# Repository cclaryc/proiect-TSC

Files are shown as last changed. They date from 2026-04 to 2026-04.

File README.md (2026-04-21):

# Overview - Hector Watch

Proiectul **Hector Watch** vizează dezvoltarea unui smartwatch, optimizat pentru consum redus de energie. Sistemul este construit în jurul microcontrolerului **nRF52840** și utilizează un afișaj de tip **e-Paper** de 1.54 inch.

### 1. Arhitectura Hardware și Selecția Componentelor
Această etapă a constat în definirea specificațiilor și alegerea componentelor pentru eficiență energetică maximă:
* **Unitate centrală:** nRF52840 (SoC cu suport BLE 5.3).
* **Afișaj:** Panou E-Ink Waveshare 1.54".
* **Senzori și Feedback:** Accelerometru Bosch BMA423 (I2C) și driver haptic TI DRV2605.
* **Sursă de energie:** Baterie Li-Po 250mAh .

## Functional Architecture

Arhitectura funcțională este proiectată pentru a maximiza eficiența energetică și a asigura o comunicare fluidă între procesorul central și perifericele specializate.

### 1. Sistemul de Management al Energiei (PMU)
Acest subsistem asigură alimentarea continuă și protecția circuitelor:
* **Input:** USB-C (5V) pentru încărcare.
* **Încărcare și Protecție:** Realizată prin IC1 , care gestionează ciclul de încărcare al bateriei Li-Po.
* **Monitorizare (Fuel Gauge): U3 raportează starea de încărcare (SoC) și tensiunea bateriei prin I2C.
* **Reglare:** IC2 (Buck-Boost) transformă tensiunea variabilă a bateriei într-o tensiune stabilă de **3.3V** pentru restul componentelor.

### 2. Procesare și Conectivitate
* **Core:** **nRF52840** (ARM Cortex-M4F) rulează logica ceasului și gestionează stack-ul de Bluetooth Low Energy (BLE).
* **Timing:** Cristale externe de 32MHz (precizie procesor) și 32.768kHz (precizie ceas/RTC în mod sleep).

### 3. Interfața Om-Mașină (HMI)
* **Output Vizual:** Ecranul **E-Ink** (cerneală electronică) reține imaginea fără consum de curent, fiind actualizat prin protocolul **SPI**. 
* **Output Haptic:** Driver-ul U2 traduce comenzile I2C în vibrații mecanice prin motorul de tip coin.
* **Input:** Trei butoane fizice (GPIO) pentru navigare și interacțiune.

### 4. Subsistemul de Senzori
* Accelerometrul **BMA423** monitorizează activitatea fizică și detectează orientarea încheieturii pentru activarea ecranului.

### Block Diagram

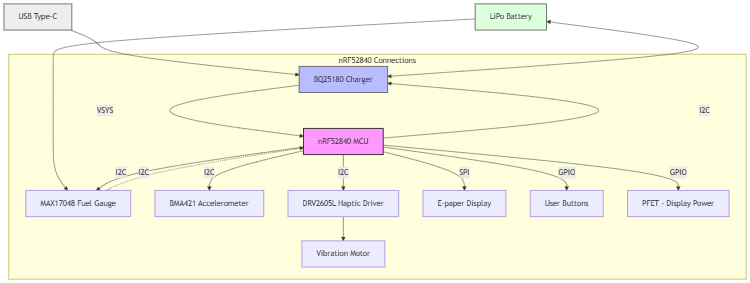
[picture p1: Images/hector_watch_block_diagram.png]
Hector Watch Block Diagram


### Matricea de Comunicație (Data Bus)

| Bus | Periferic | Tip | Rol |
| :--- | :--- | :--- | :--- |
| **SPI** | E-Paper Display | Master -> Slave | Transfer rapid de buffere de imagine |
| **I2C** | BMA423, DRV2605, MAX17048, BQ25180 | Multimaster | Configurare senzori și citire telemetrie baterie |
| **GPIO** | Butoane, Display Power (PFET), Motor EN | Digital I/O | Control direct și evenimente asincrone |

### Bill of Materials

| Referință | Componentă | Funcție | Package | JLC Code | Datasheet |
| :--- | :--- | :--- | :--- | :--- | :--- |
| **IC1 (U1)** | nRF52840-QIAA | Procesor principal (MCU) și controller Bluetooth. | aQFN73 | C190740 | [Link](https://jlcpcb.com/api/file/downloadByFileSystemAccessId/8588884082339532800) |
| **IC2 (U2)** | BQ25180YBGR | Încărcător de baterie inteligent. | WLCSP-8 | C2907431 | [Link](https://www.ti.com/cn/lit/gpn/bq25180) |
| **IC3 (U3)** | MAX17048G+T10 | Monitorizează nivelul bateriei (Fuel Gauge). | TDFN-8 | C72035 | [Link](https://jlc-prod-smt.oss-eu-central-1.aliyuncs.com/smtDataManualFile/8588907428515614720-C2682616.pdf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) |
| **IC4 (U4)** | DRV2605YZFR | Driver specializat pentru efecte haptice. | BGA-9 | C156475 | [Link](https://www.ti.com/cn/lit/gpn/drv2605) |
| **IC5 (U5)** | BMA423 | Senzor de mișcare (pași/gesturi). | LGA-12 | C406450 | [Link](https://jlc-prod-smt.oss-eu-central-1.aliyuncs.com/smtDataManualFile/8588894317138628608-C189517.pdf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) |
| **IC6 (U6)** | RT6160AWSC | Regulator Buck-Boost (3.3V stabil). | WLCSP-15 | C141692 | [Link](https://jlcpcb.com/api/file/downloadByFileSystemAccessId/8600398231234883584) |
| **IC7 (U7)** | USBLC6-2SC6Y | Protecție ESD la mufa USB. | SOT-23-6L | C7519 | [Link](https://jlc-prod-smt.oss-eu-central-1.aliyuncs.com/smtDataManualFile/8603165824283140096-C2969755.pdf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) |
| **X1** | ECS-320-10-33B | Cristal 32MHz pentru Bluetooth. | 3225 SMD | C110292 | [Link](https://www.google.com/search?q=https://ecsxtal.com/store/pdf/ECS-320-10-33B-CKM.pdf) |
| **X2** | NX3215SA | Cristal 32.768kHz pentru RTC. | 3215 SMD | C32156 | [Link](https://www.ndk.com/images/products/catalog/c_NX3215SA_e.pdf) |
| **D1** | MBR0530 | Diodă Schottky pentru protecție curent. | SOD-123 | C8200 | [Link](https://www.onsemi.com/pdf/datasheet/mbr0530t1-d.pdf) |
| **D2-D5** | Generic 0402 | LED-uri stare (încărcare/notificări). | 0402 SMD | - | - |
| **L1** | MLP2016H2R2MT | Inductor Power pentru RT6160. | 2016 SMD | C135431 | [Link](https://product.tdk.com/system/files/dam/doc/product/inductor/inductor/smd/catalog/inductor_commercial_power_mlp2016_en.pdf) |
| **Q1** | SI1308EDL | Switch logic pentru alimentare display. | SOT-23 | C140222 | [Link](https://www.vishay.com/docs/63399/si1308edl.pdf) |
| **Resistors** | C3920633 | Pull-up I2C și limitare LED. | 0201 | **C3920633** | - |
| **Capacitors**| C9900156064 | Filtrare și decuplare generală. | 0201 | **C9900156064** | - |
| **C23, 27..** | C21012218 | Stabilitate tensiune. | - | **C21012218** | - |
| **C24, 25..** | C9900179830 | Filtrare intrare/ieșire putere. | 0402 | **C9900179830** | - |
| **DISP** | Waveshare 1.54" | Ecran principal E-Ink. | 37.3x31.8 mm | - | [Link PDF](https://www.waveshare.com/w/upload/7/77/1.54inch_e-Paper_Datasheet.pdf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) |
| **BATT** | Akyga LP502030 | Sursă energie (250mAh). | 32.5x21 mm | - | [Link](https://files.elektroniksc.com.pl/14017-2427914986/LP502030.pdf) |
| **MOT** | FIT0774 | Motor vibrații haptic. | Ø10 x 3 mm | - | [Link](https://jlc-prod-smt.oss-eu-central-1.aliyuncs.com/smtDataManualFile/8600542373223424000-C17569954.pdf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) |
| **USB** | KH-TYPE-C-16P | Port încărcare și date USB-C. | 16-pin SMD | C165948 | [Link](https://www.snapeda.com/parts/KH-TYPE-C-16P/kinghelm/datasheet/) |
| **J1** | 503480-2400 | Conector FPC (Display). | 0.5mm Pitch | C262524 | [Link](https://www.molex.com/en-us/products/part-detail/5034802400) |
| **ANT** | 2450AT18B100E | Antenă Bluetooth 2.4GHz. | 3216 SMD | C105151 | [Link](https://www.johansontechnology.com/datasheets/2450AT18B100.pdf) |
| **BTN** | EVP-AKE31A | Butoane navigare meniu. | 3.8x1.9 mm | C138127 | [Link](hhttps://jlc-prod-smt.oss-eu-central-1.aliyuncs.com/smtDataManualFile/8588931144787611648-C569760.pdf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) |
| **PROG** | TC2030-IDC | Interfață programare (Tag-Connect). | Plug-of-Nails | - | [Link](https://www.snapeda.com/parts/TC2030-IDC/Tag-Connect%20LLC/datasheet/) |

## nRF52840 Pin Mapping

### 1. Magistrala I2C (Senzori și Management Energie)
Această magistrală este utilizată pentru comunicarea cu majoritatea componentelor inteligente din sistem.
* **P0.26:** Linia de date **SDA**. Conectează:
    * **IC1** (Charger BQ25180)
    * **IC3** (IMU BMA421)
    * **U3** (Fuel Gauge MAX17048)
    * **IC2** (Haptic Driver DRV2605)
* **P0.27:** Linia de ceas **SCL**

### 2. Interfața SPI și Control (E-Paper Display)
Conexiunile către conectorul **J1** (E-Paper Display Connector)
* **P0.05:** EPD_SCK (Ceas SPI).
* **P0.07:** EPD_MOSI (Date SPI)
* **P0.12:** EPD_CS (Chip Select)
* **P0.11:** EPD_DC (Data/Command control)
* **P0.04:** EPD_RST (Reset Display).
* **P0.08:** EPD_BUSY (Semnal stare display).
* **P0.31:** **PWR_EPD_CTRL** – Controlează tranzistorul **Q1** pentru a activa/dezactiva alimentarea întregului circuit de display

### 3. Interfață Utilizator (Butoane și Haptic)
* **P1.00:** Buton **SW_UP**
* **P1.01:** Buton **SW_ENT** (Enter/Select)
* **P1.02:** Buton **SW_DN** (Down)
* **P0.29:** **HAPTIC_EN / INTRIG** – Pinul de declanșare pentru driverul de vibrații **IC2**

### 4. Sistem și Debug
* **P0.18 / RESET:** Pinul de reset hardware, conectat la interfața de programare.
* **SWDIO / SWCLK:** Pinii de programare și depanare prin interfața **SWD**, conectați la mufa **TC2030**
* **ANT:** Pinul dedicat pentru ieșirea radio, conectat la antena chip de 2.4GHz (**ANT1**)

### 5. Alimentare (Power Rails)
* **VDD / VDDH:** Alimentarea principală de **3.3V** provenită de la regulatorul DC/DC
* **VSS:** Conexiunile la masă (**GND**)

## Design Considerations
* **Componente doar pe TOP:** Toate piesele sunt pe o singură față pentru asamblare rapidă și ieftină.
* **Plane de GND:** Cupru pe ambele părți pentru protecție și semnal fără zgomot.
* **Via stitching:** Găuri multe lângă antenă pentru a bloca interferențele radio.
* **Decuplare:** Condensatori puși fix lângă pini pentru un curent cât mai stabil.
* **Keepout antenă:** Zonă fără cupru sub antenă pentru semnal Bluetooth maxim.
* **Baterie fără JST:** Baterie lipită direct, fără mufă, pentru a face ceasul cât mai subțire.

## Design Rule Check (DRC) Exceptions
| Tip eroare | Componentă | Explicație simplă |
| --- | --- | --- |
| Solid Polygon Shape - Pad Overlap  | Butoane tactile / planuri de cupru | Suprapunerea este din cauza amplasarii butoanelor. |
| SMD-Via Overlap | nRF52840 (CPU) | Via-in-pad este necesar la acest procesor, fiindcă are pini mulți și spațiu foarte mic. |
| Wire Copper Width | Trasee de putere / intrări componente | Traseele se îngustează local ca să poată intra între pini fără să facă scurt.  [necking] |
| Wire/Via Copper Clearance | Rutare internă CPU | Distanțele sunt mai mici din lipsă de spațiu, dar sunt încă în limitele acceptate de fabricație. |
| SMD-Hole / Board Outline Clearance | USB Type-C / margine PCB | Conectorul USB-C este pus aproape de margine pentru a se potrivi corect cu decupajul carcasei. |

## Hardware Renderings & Visuals
### Final PCB Layout
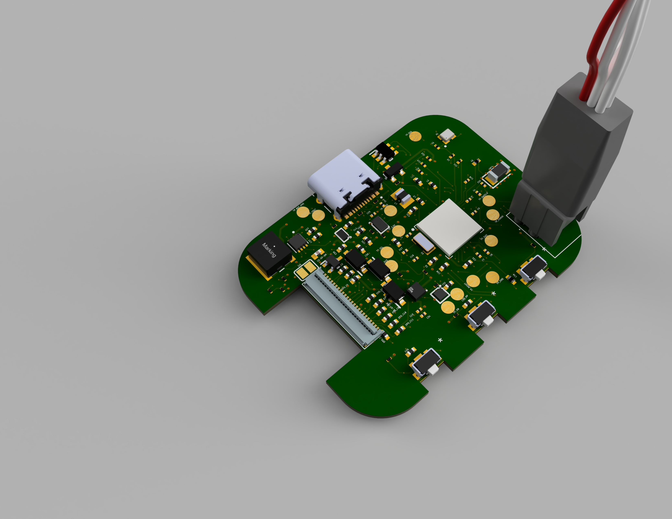
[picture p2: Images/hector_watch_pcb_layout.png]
Hector Watch PCB Layout

### Final Design Render
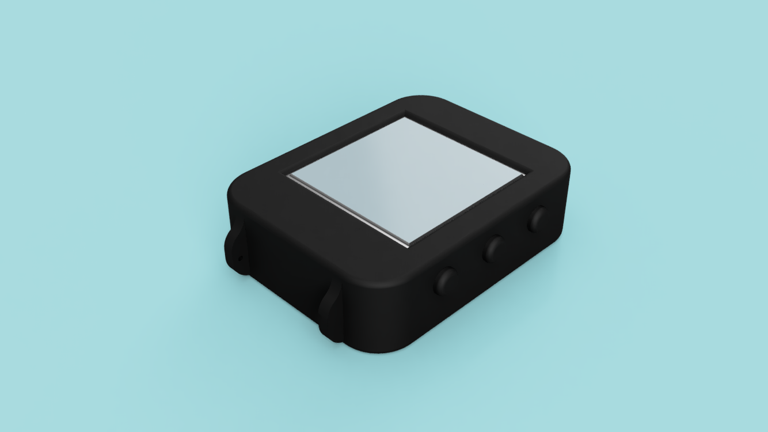
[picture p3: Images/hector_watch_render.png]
Hector Watch Render

### Final Design Explored
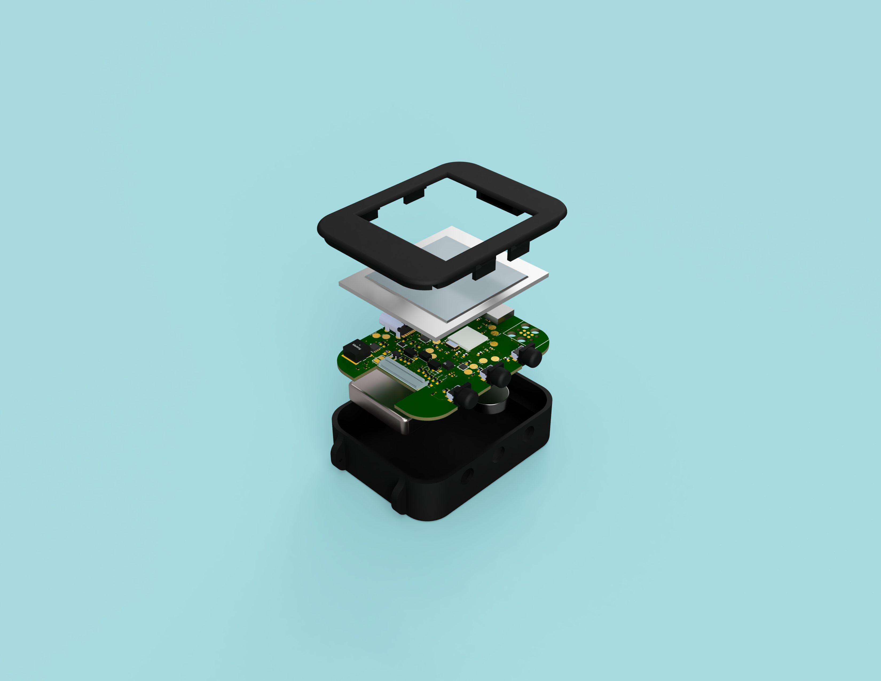
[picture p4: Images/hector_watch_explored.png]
E-Paper Display


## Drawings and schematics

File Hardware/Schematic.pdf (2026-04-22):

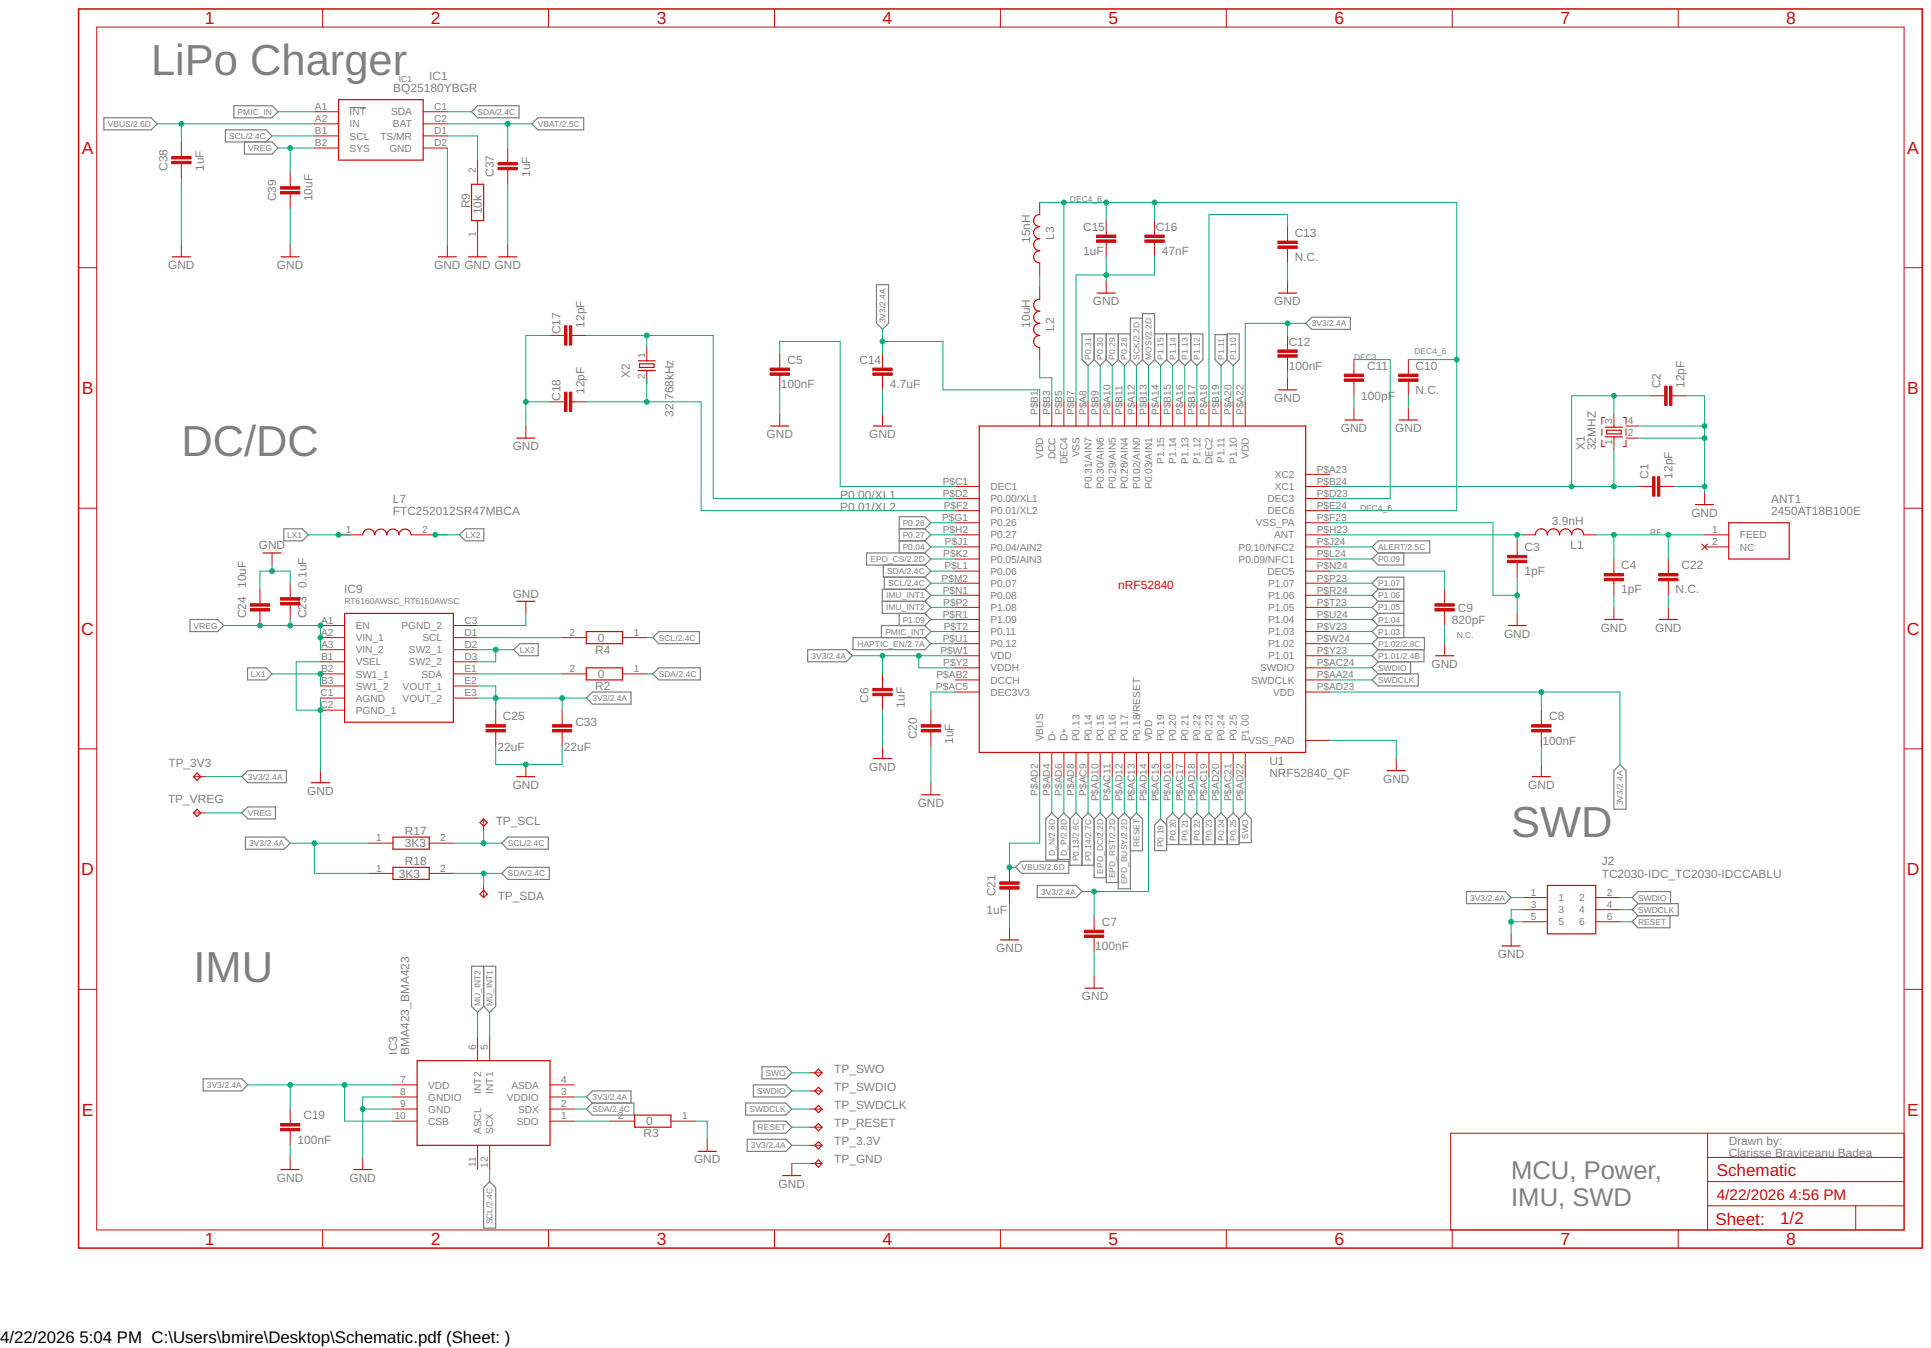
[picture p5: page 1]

Drawn by: Clarisse Braviceanu Badea
Schematic
Sheet: 1/2

4/22/2026 5:04 PM C:\Users\bmire\Desktop\Schematic.pdf (Sheet: )

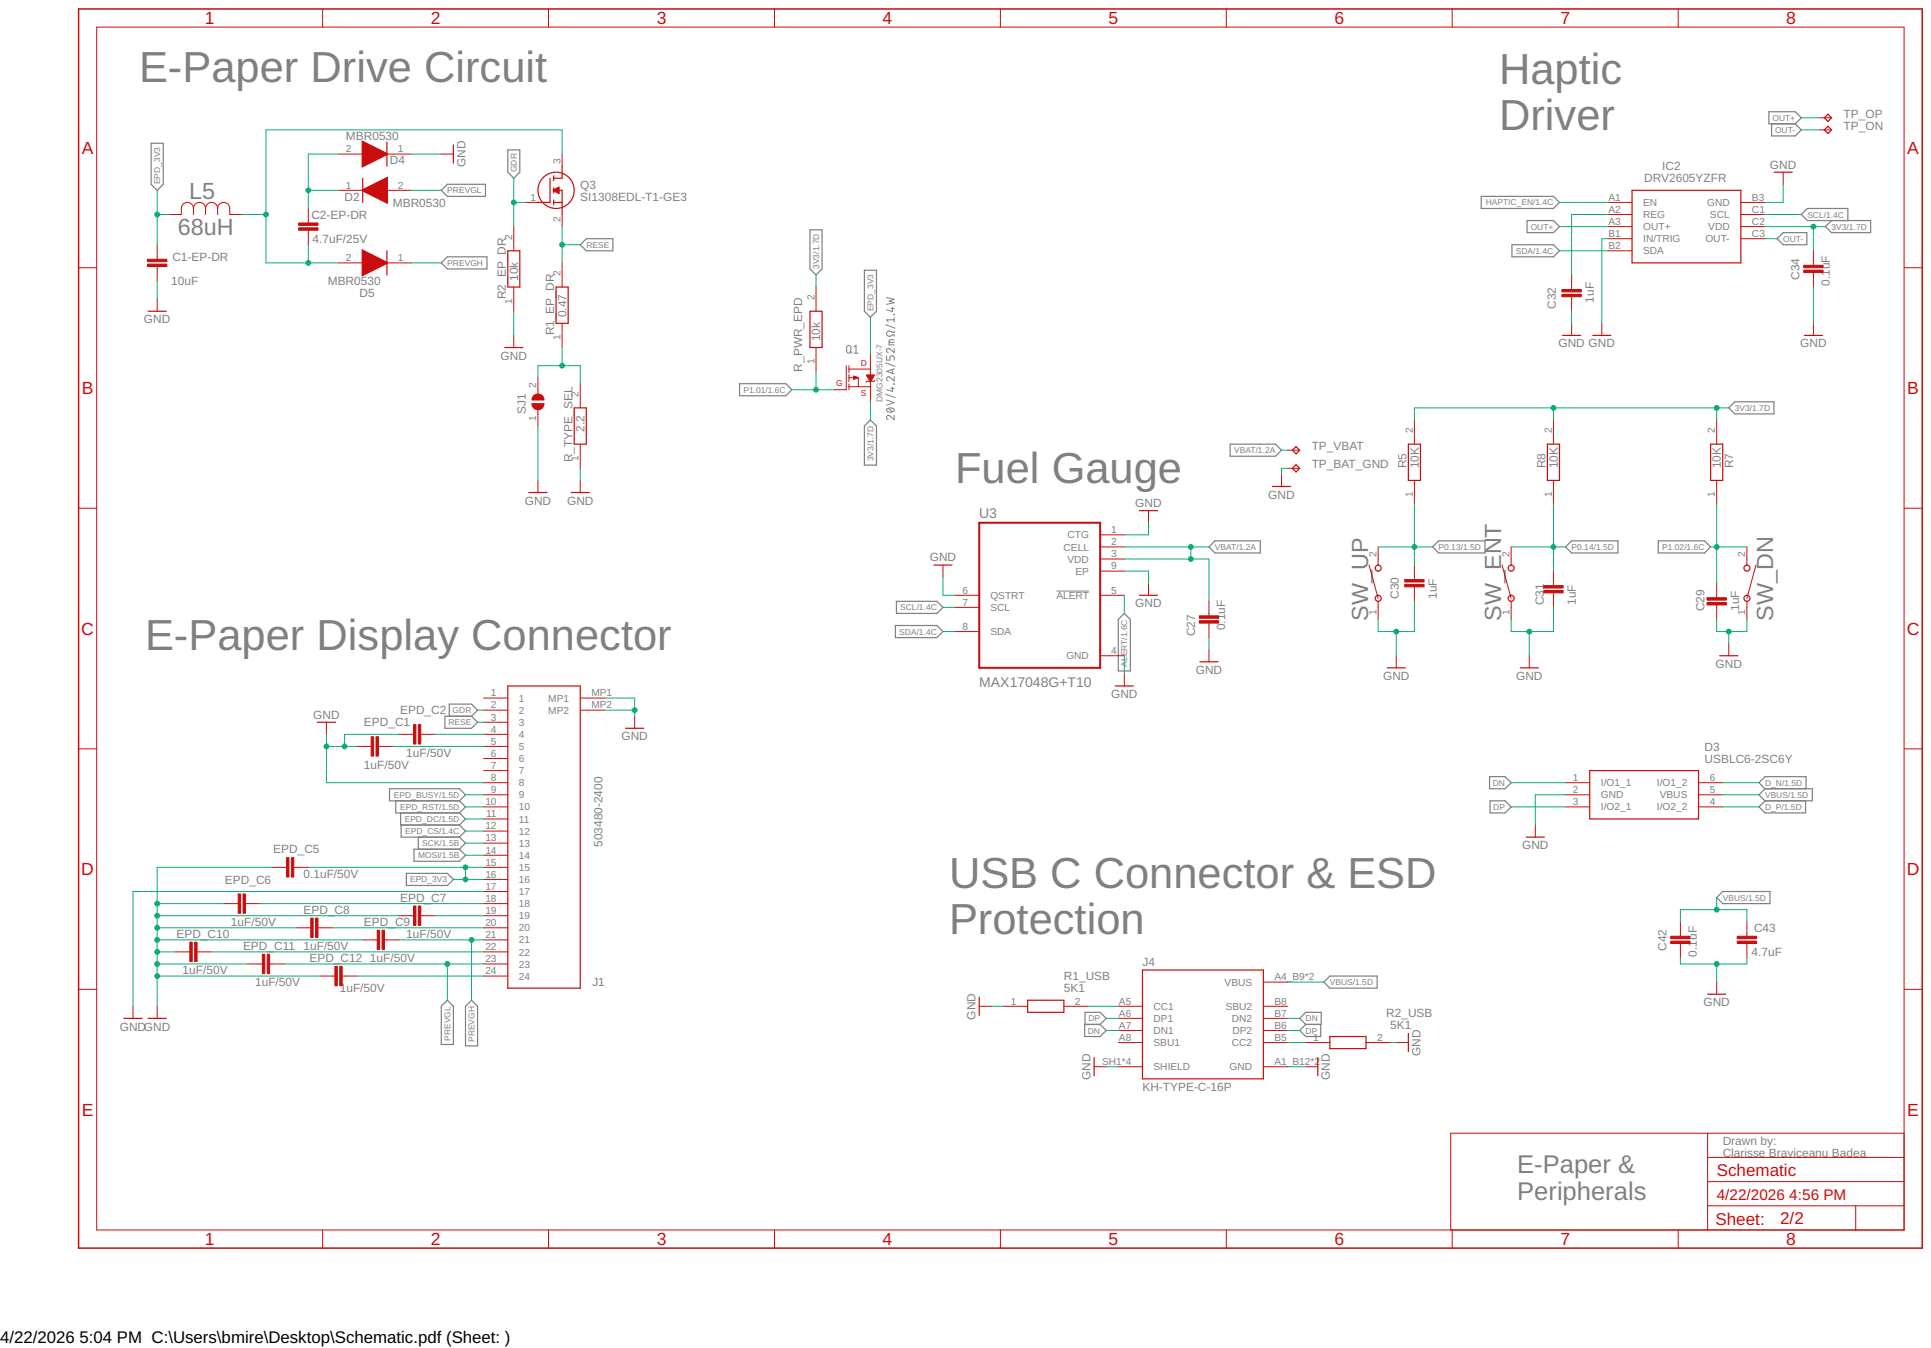
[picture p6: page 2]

EPD_C7 18

EPD_C8 | 19

1uF/50V | EPD_C9 | 20
EPD_C11 1uF/50V | | 22

EPD_C10 | | 1uF/50V 21

EPD_C12 1uF/50V | 23

Drawn by: Clarisse Braviceanu Badea
Schematic
Sheet: 2/2

4/22/2026 5:04 PM C:\Users\bmire\Desktop\Schematic.pdf (Sheet: )

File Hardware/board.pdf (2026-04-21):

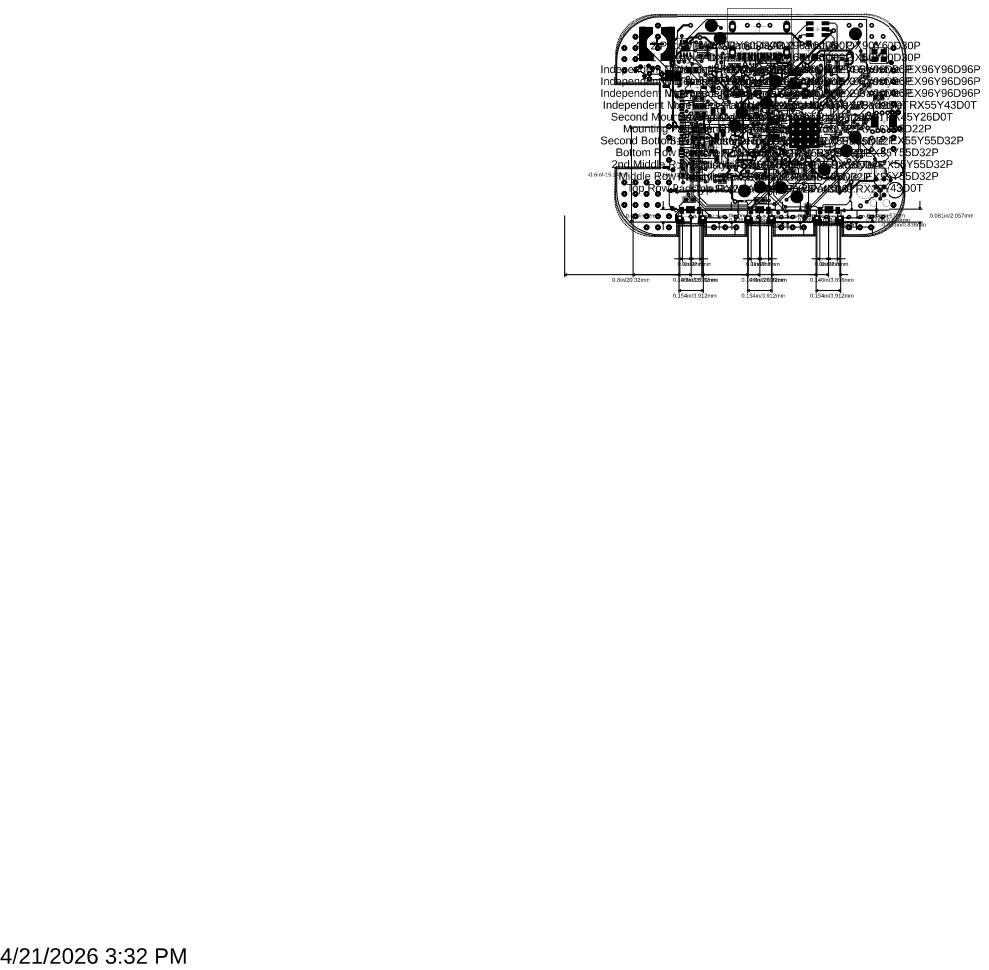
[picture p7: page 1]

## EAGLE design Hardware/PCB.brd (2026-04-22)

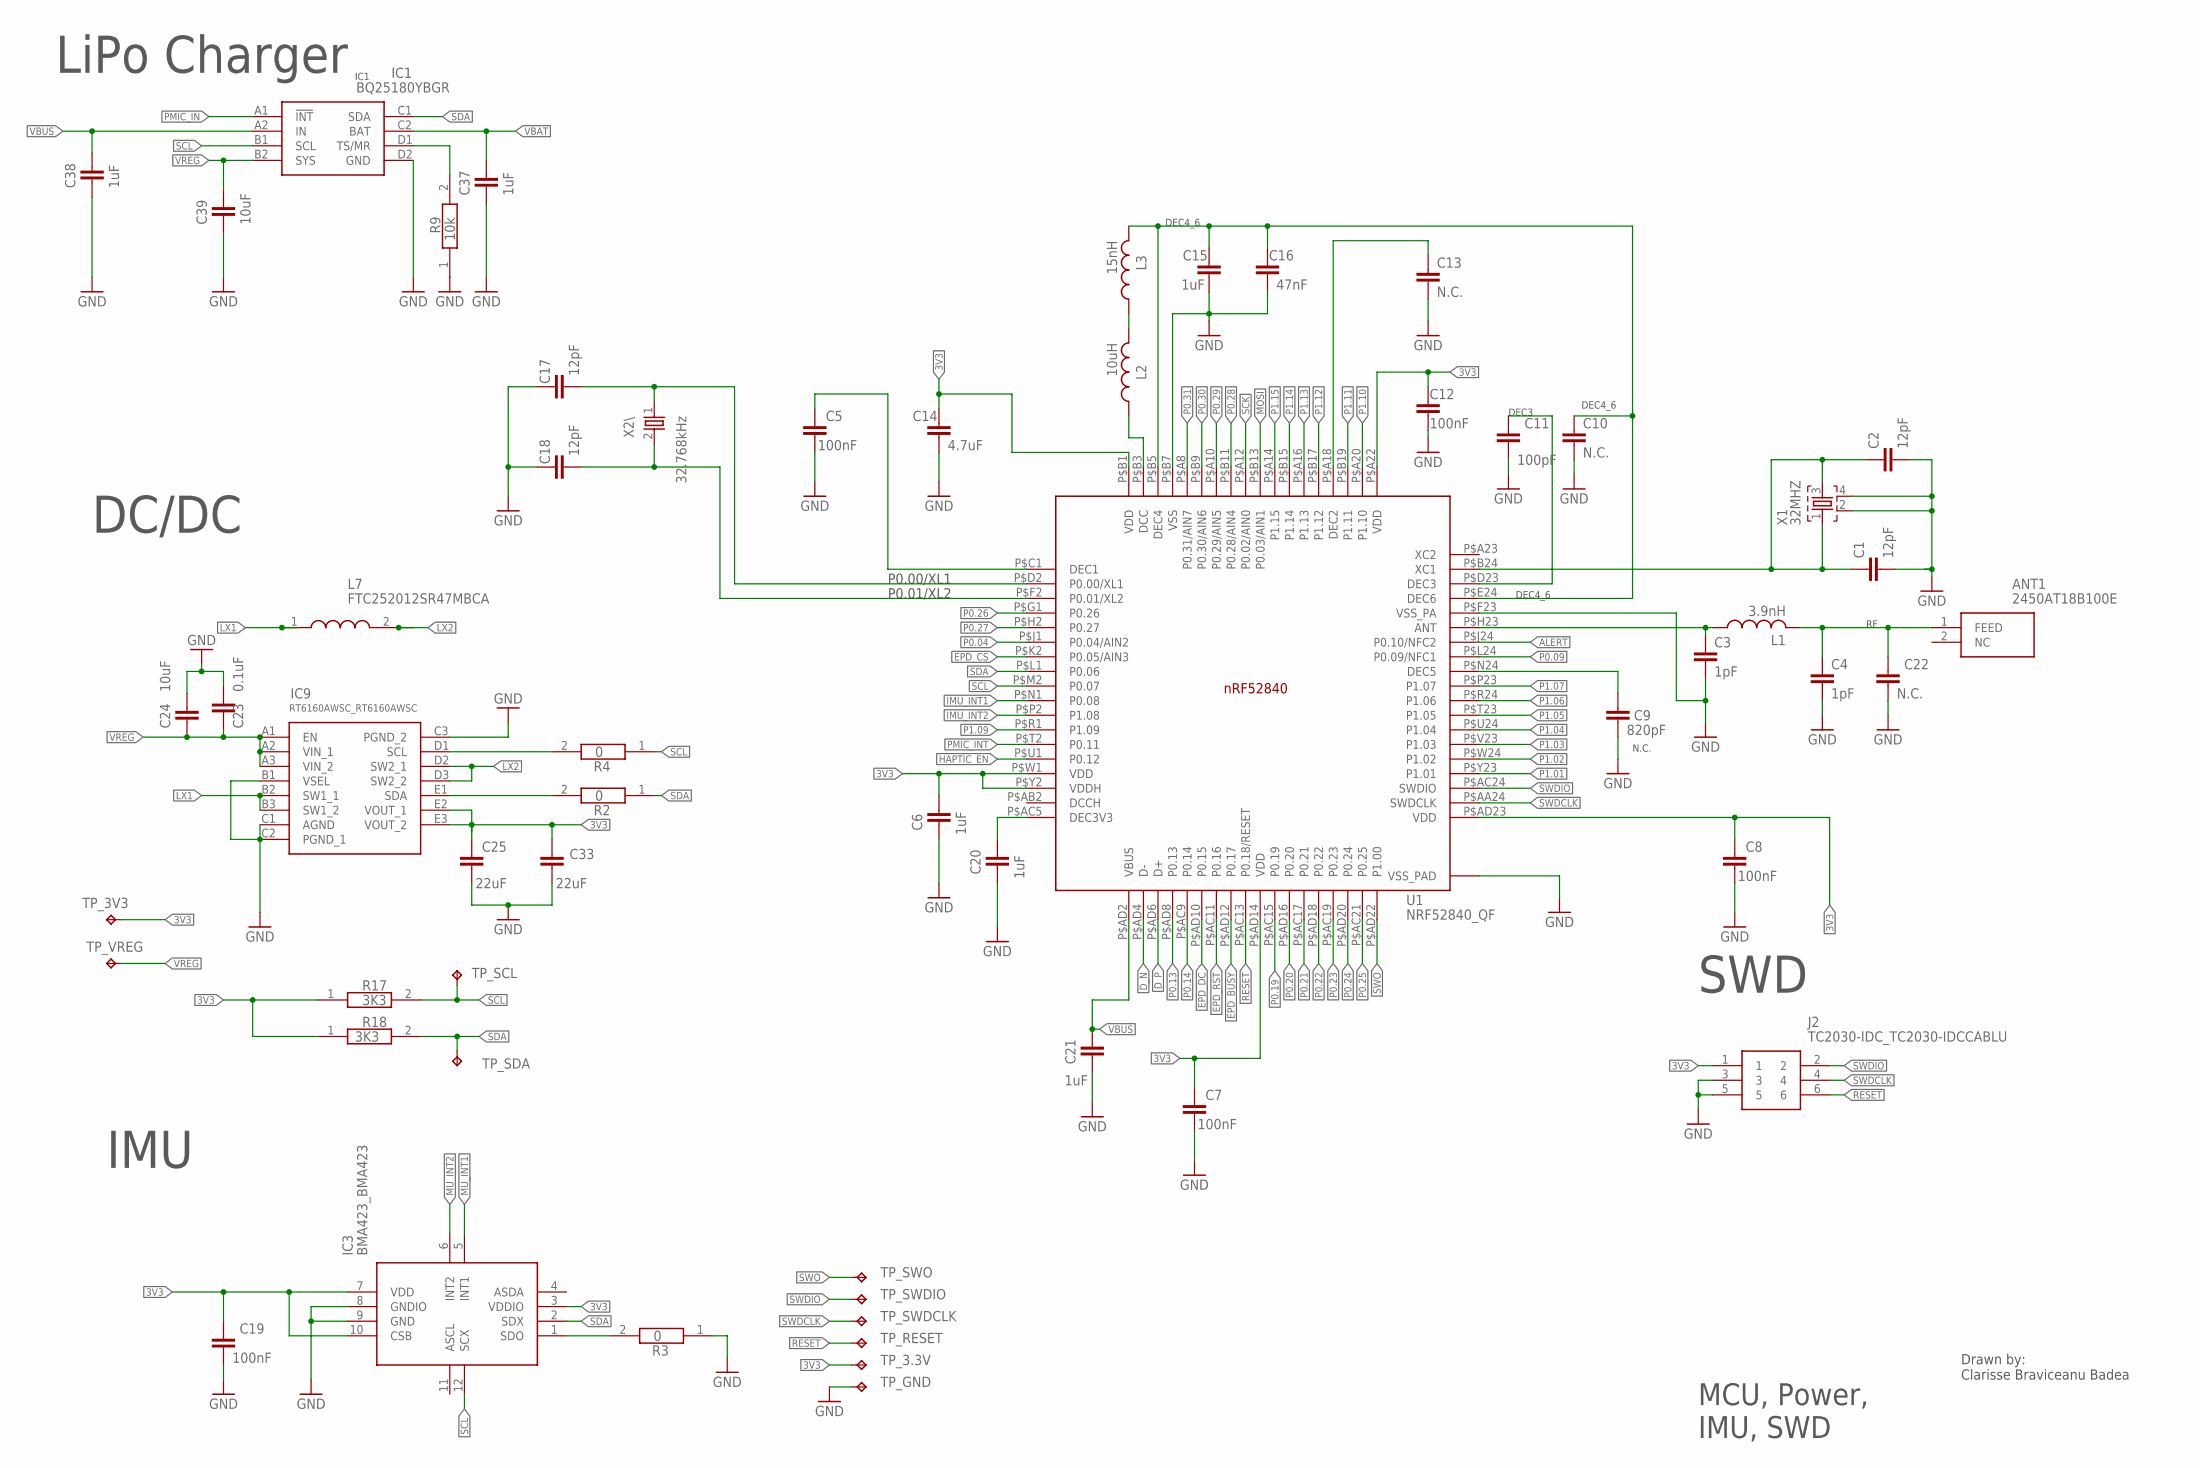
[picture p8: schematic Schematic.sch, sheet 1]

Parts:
ANT1: 2450AT18B100E; 2450AT18B100E_ANTC3216X140N
C1, C2, C17, C18: 12pF; NORDIC_NRF_3_RESC0201_N
C3, C4: 1pF; NORDIC_NRF_3_RESC0201_N
C5, C7, C8, C12, C19: 100nF; NORDIC_NRF_3_RESC0201_N
C6, C15, C20, C21, C37, C38: 1uF; NORDIC_NRF_3_RESC0402_N
C9: 820pF; NORDIC_NRF_3_RESC0201_N
C10, C13, C22: N.C.; NORDIC_NRF_3_RESC0201_N
C11: 100pF; NORDIC_NRF_3_RESC0201_N
C14: 4.7uF; NORDIC_NRF_3_RESC0402_N
C16: 47nF; NORDIC_NRF_3_RESC0201_N
C23: 0.1uF; NORDIC_NRF_3_RESC0201_N
C24, C39: 10uF; NORDIC_NRF_3_RESC0402_N
C25, C33: 22uF; NORDIC_NRF_3_RESC0402_N
IC1: BQ25180YBGR; BQ25180YBGR_BGA8C40P2X4_100X155X50
IC3: BMA423_BMA423
IC9: RT6160AWSC_RT6160AWSC; RT6160AWSC_BGA15C40P3X5_140X230X60
J2: TC2030-IDC_TC2030-IDCCABLU; TC2030-IDC_TC2030IDC
L1: 3.9nH; NORDIC_NRF_2_RESC0402_L
L2: 10uH; NORDIC_NRF_2_RESC0402_L
L3: 15nH; NORDIC_NRF_2_RESC0402_L
L7: FTC252012SR47MBCA; MLP2016SR47MT0S1_INDC2016X100N
R2, R3, R4: 0; CPF0201D7K68C1_0201
R9: 10k; CPF0201D7K68C1_0201
R17, R18: 3K3; CPF0201D7K68C1_0201
TP_3.3V, TP_3V3: HECTOR_WATCH_1_TPTP20R; HECTOR_WATCH_1_TP20R
TP_GND: HECTOR_WATCH_1_TPTP20R; HECTOR_WATCH_1_TP20R
TP_RESET: HECTOR_WATCH_1_TPTP20R; HECTOR_WATCH_1_TP20R
TP_SCL: HECTOR_WATCH_1_TPTP20R; HECTOR_WATCH_1_TP20R
TP_SDA: HECTOR_WATCH_1_TPTP20R; HECTOR_WATCH_1_TP20R
TP_SWDCLK: HECTOR_WATCH_1_TPTP20R; HECTOR_WATCH_1_TP20R
TP_SWDIO: HECTOR_WATCH_1_TPTP20R; HECTOR_WATCH_1_TP20R
TP_SWO: HECTOR_WATCH_1_TPTP20R; HECTOR_WATCH_1_TP20R
TP_VREG: HECTOR_WATCH_1_TPTP20R; HECTOR_WATCH_1_TP20R
U1: NRF52840_QF; NORDIC_NRF_4_AQFN50P700X700X85_HS-74N
X1: 32MHZ; NORDIC_NRF_BT-XTAL_2016_N
X2\: 32.768kHz; NORDIC_NRF_1_XTAL_3215_N

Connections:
3V3: C6.1, C7.1, C8.1, C12.2, C14.1, C19.2, C25.1, C33.1, IC3.3 (VDDIO), IC3.7 (VDD), IC3.10 (CSB), IC9.E2 (VOUT_1), IC9.E3 (VOUT_2), J2.1, R17.1, R18.1, TP_3.3V.TP, TP_3V3.TP, U1.P$A22 (VDD), U1.P$AD14 (VDD), U1.P$AD23 (VDD), U1.P$B1 (VDD), U1.P$W1 (VDD), U1.P$Y2 (VDDH); also elsewhere on the board
ALERT: U1.P$J24 (P0.10/NFC2); also elsewhere on the board
D_N: U1.P$AD4 (D-); also elsewhere on the board
D_P: U1.P$AD6 (D+); also elsewhere on the board
EPD_BUSY: U1.P$AD12 (P0.17); also elsewhere on the board
EPD_CS: U1.P$K2 (P0.05/AIN3); also elsewhere on the board
EPD_DC: U1.P$AD10 (P0.15); also elsewhere on the board
EPD_RST: U1.P$AC11 (P0.16); also elsewhere on the board
GND: C1.2, C2.2, C3.1, C4.1, C5.2, C6.2, C7.2, C8.2, C9.1, C10.1, C11.1, C12.1, C13.1, C14.2, C15.2, C16.1, C17.1, C18.1, C19.1, C20.2, C21.2, C22.1, C23.1, C24.1, C25.2, C33.2, C37.2, C38.2, C39.2, IC1.D2 (GND), IC3.8 (GNDIO), IC3.9 (GND), IC9.B1 (VSEL), IC9.C1 (AGND), IC9.C2 (PGND_1), IC9.C3 (PGND_2), J2.3, J2.5, R3.1, R9.1, TP_GND.TP, U1.P$74 (VSS_PAD), U1.P$75 (VSS_PAD), U1.P$76 (VSS_PAD), U1.P$77 (VSS_PAD), U1.P$78 (VSS_PAD), U1.P$79 (VSS_PAD), U1.P$80 (VSS_PAD), U1.P$81 (VSS_PAD), U1.P$82 (VSS_PAD), U1.P$83 (VSS_PAD), U1.P$84 (VSS_PAD), U1.P$85 (VSS_PAD), U1.P$86 (VSS_PAD), U1.P$87 (VSS_PAD), U1.P$88 (VSS_PAD), U1.P$89 (VSS_PAD), U1.P$90 (VSS_PAD), U1.P$B7 (VSS), U1.P$F23 (VSS_PA), X1.2, X1.4; also elsewhere on the board
HAPTIC_EN: U1.P$U1 (P0.12); also elsewhere on the board
IMU_INT1: U1.P$N1 (P0.08)
IMU_INT2: U1.P$P2 (P1.08)
LX1: IC9.B2 (SW1_1), IC9.B3 (SW1_2), L7.1
LX2: IC9.D2 (SW2_1), IC9.D3 (SW2_2), L7.2
MOSI: U1.P$B13 (P0.03/AIN1); also elsewhere on the board
MU_INT1: IC3.5 (INT1)
MU_INT2: IC3.6 (INT2)
unnamed: C3.2, L1.1, U1.P$H23 (ANT)
unnamed: ANT1.1 (FEED), C4.2, C22.2, L1.2
unnamed: C11.2, U1.P$D23 (DEC3)
unnamed: C1.1, C2.1, U1.P$B24 (XC1), X1.1, X1.3
unnamed: C9.2, U1.P$N24 (DEC5)
unnamed: L2.1, U1.P$B3 (DCC)
unnamed: IC1.D1 (TS/MR), R9.2
unnamed: IC9.D1 (SCL), R4.2
unnamed: IC9.E1 (SDA), R2.2
unnamed: IC3.1 (SDO), R3.2
unnamed: C5.1, U1.P$C1 (DEC1)
unnamed: C17.2, U1.P$D2 (P0.00/XL1), X2\.1
unnamed: C20.1, U1.P$AC5 (DEC3V3)
unnamed: C18.2, U1.P$F2 (P0.01/XL2), X2\.2
unnamed: L2.2, L3.1
unnamed: C10.2, C15.1, C16.2, L3.2, U1.P$B5 (DEC4), U1.P$E24 (DEC6)
unnamed: C13.2, U1.P$A18 (DEC2)
P0.04: U1.P$J1 (P0.04/AIN2)
P0.09: U1.P$L24 (P0.09/NFC1)
P0.13: U1.P$AD8 (P0.13); also elsewhere on the board
P0.14: U1.P$AC9 (P0.14); also elsewhere on the board
P0.19: U1.P$AC15 (P0.19)
P0.20: U1.P$AD16 (P0.20)
P0.21: U1.P$AC17 (P0.21)
P0.22: U1.P$AD18 (P0.22)
P0.23: U1.P$AC19 (P0.23)
P0.24: U1.P$AD20 (P0.24)
P0.25: U1.P$AC21 (P0.25)
P0.26: U1.P$G1 (P0.26)
P0.27: U1.P$H2 (P0.27)
P0.28: U1.P$B11 (P0.28/AIN4)
P0.29: U1.P$A10 (P0.29/AIN5)
P0.30: U1.P$B9 (P0.30/AIN6)
P0.31: U1.P$A8 (P0.31/AIN7)
P1.01: U1.P$Y23 (P1.01); also elsewhere on the board
P1.02: U1.P$W24 (P1.02); also elsewhere on the board
P1.03: U1.P$V23 (P1.03)
P1.04: U1.P$U24 (P1.04)
P1.05: U1.P$T23 (P1.05)
P1.06: U1.P$R24 (P1.06)
P1.07: U1.P$P23 (P1.07)
P1.09: U1.P$R1 (P1.09)
P1.10: U1.P$A20 (P1.10)
P1.11: U1.P$B19 (P1.11)
P1.12: U1.P$B17 (P1.12)
P1.13: U1.P$A16 (P1.13)
P1.14: U1.P$B15 (P1.14)
P1.15: U1.P$A14 (P1.15)
PMIC_IN: IC1.A1 (!INT)
PMIC_INT: U1.P$T2 (P0.11)
RESET: J2.6, TP_RESET.TP, U1.P$AC13 (P0.18/RESET)
SCK: U1.P$A12 (P0.02/AIN0); also elsewhere on the board
SCL: IC1.B1 (SCL), IC3.12 (SCX), R4.1, R17.2, TP_SCL.TP, U1.P$M2 (P0.07); also elsewhere on the board
SDA: IC1.C1 (SDA), IC3.2 (SDX), R2.1, R18.2, TP_SDA.TP, U1.P$L1 (P0.06); also elsewhere on the board
SWDCLK: J2.4, TP_SWDCLK.TP, U1.P$AA24 (SWDCLK)
SWDIO: J2.2, TP_SWDIO.TP, U1.P$AC24 (SWDIO)
SWO: TP_SWO.TP, U1.P$AD22 (P1.00)
VBAT: C37.1, IC1.C2 (BAT); also elsewhere on the board
VBUS: C21.1, C38.1, IC1.A2 (IN), U1.P$AD2 (VBUS); also elsewhere on the board
VREG: C23.2, C24.2, C39.1, IC1.B2 (SYS), IC9.A1 (EN), IC9.A2 (VIN_1), IC9.A3 (VIN_2), TP_VREG.TP

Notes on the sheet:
DC/DC
SWD
N.C.
DEC3
DEC4_6
LiPo Charger
IMU
Drawn by: Clarisse Braviceanu Badea
IC1
MCU, Power, IMU, SWD
P0.00/XL1
P0.01/XL2

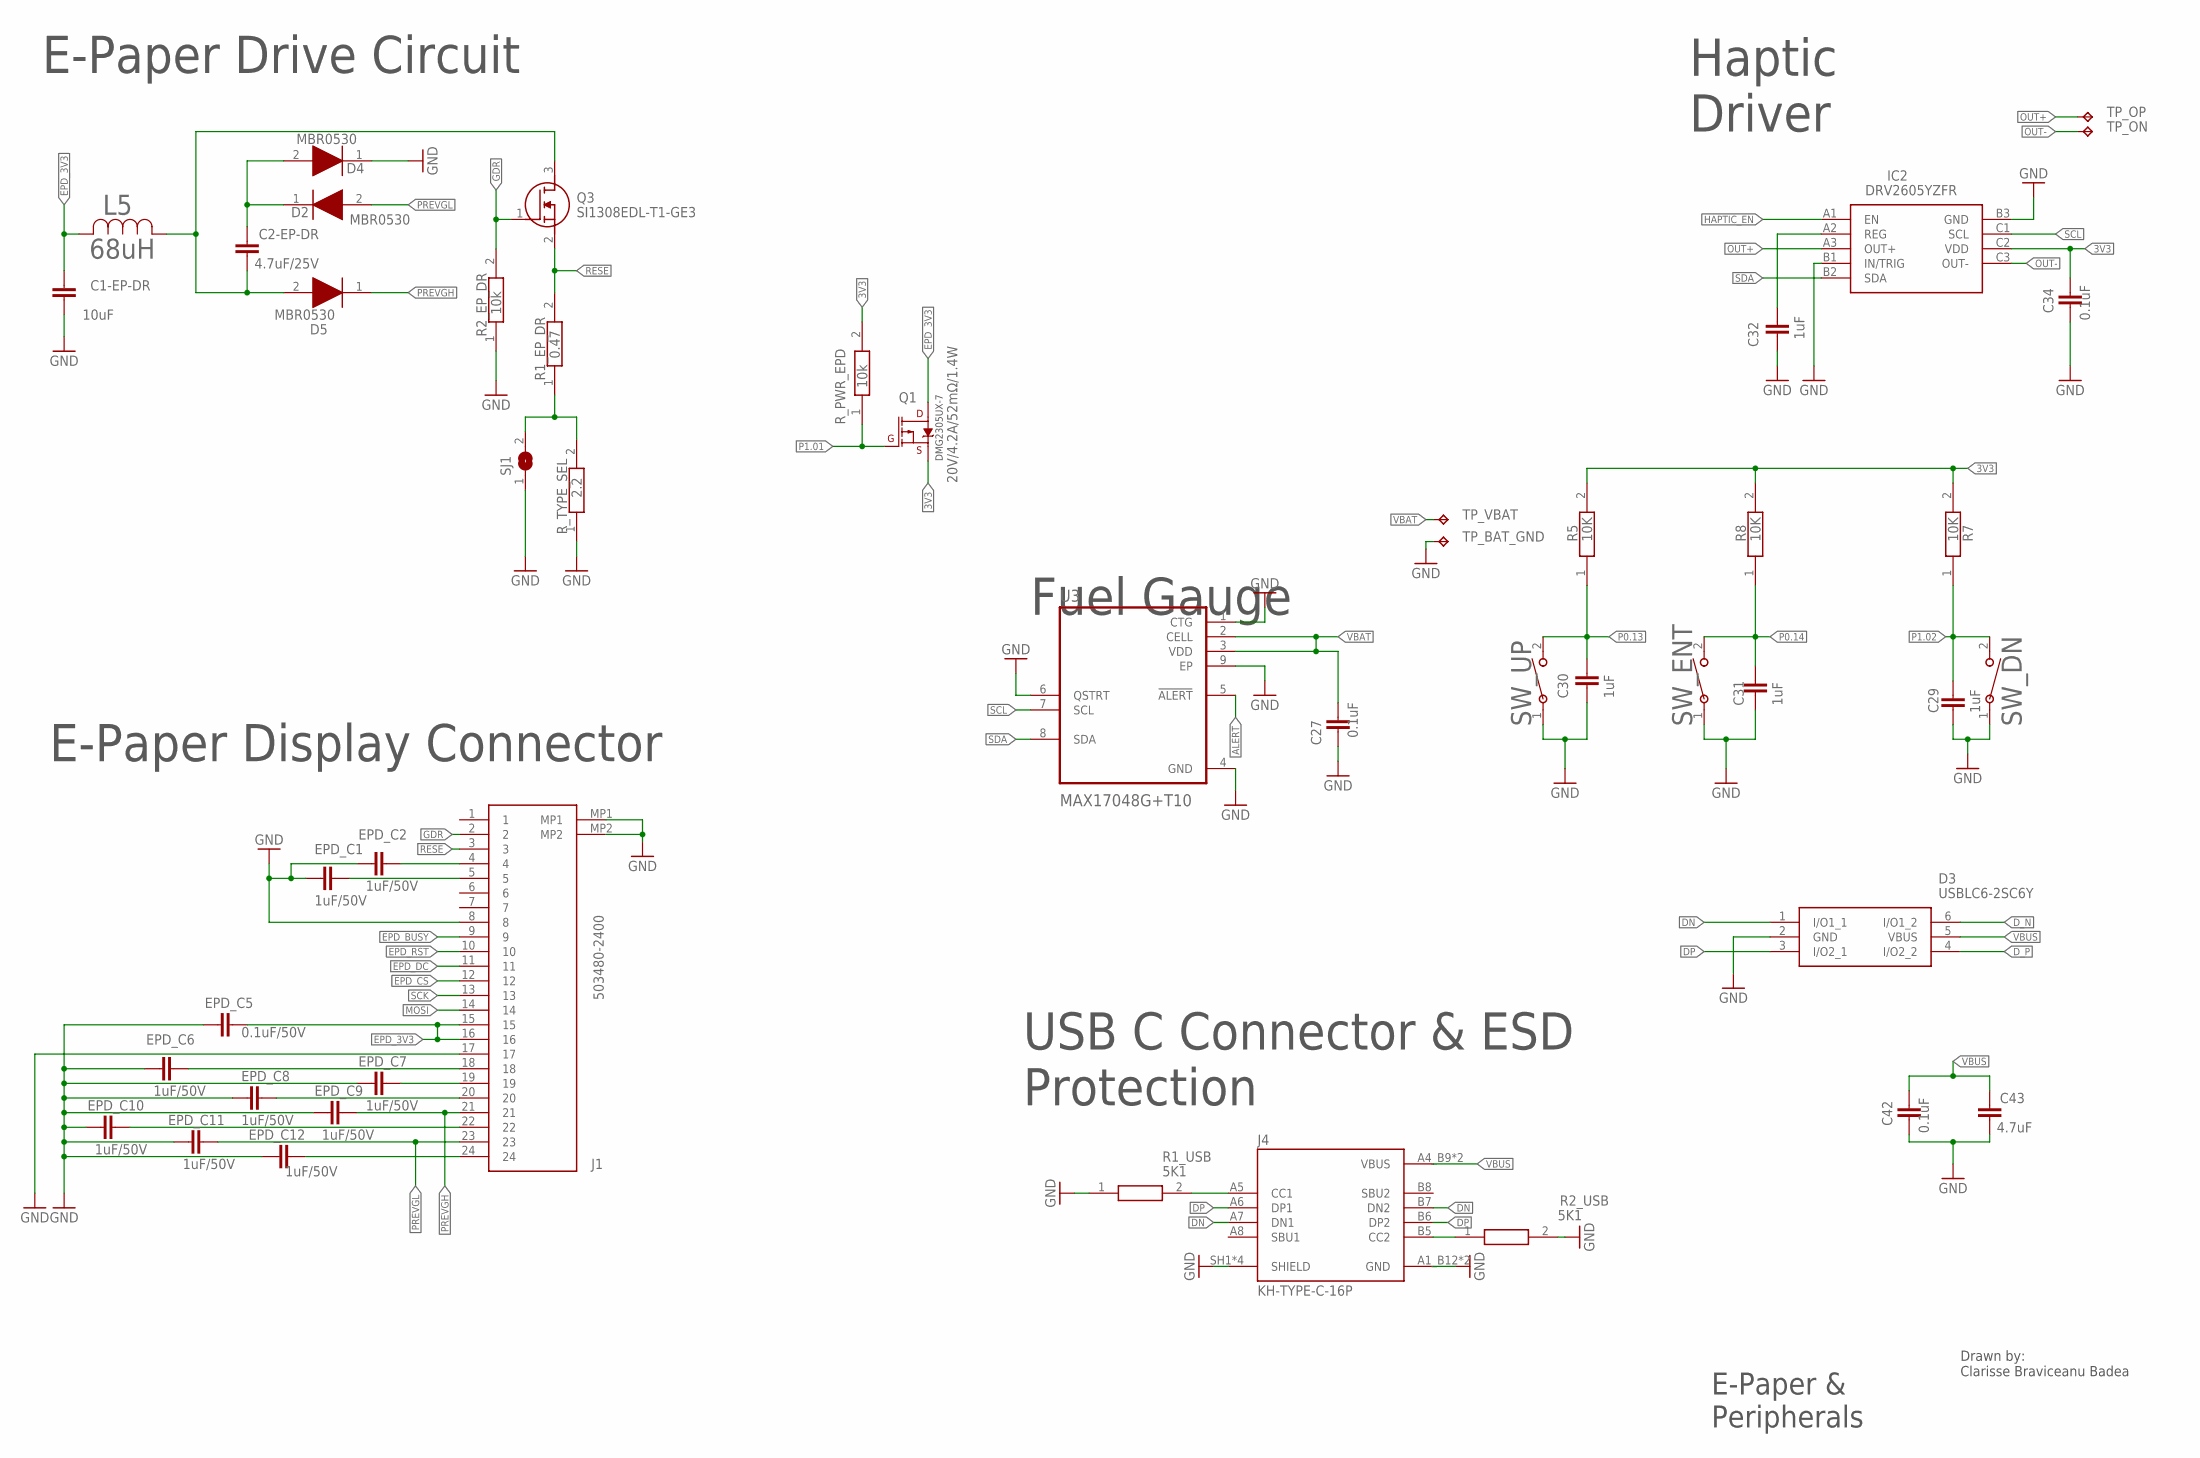
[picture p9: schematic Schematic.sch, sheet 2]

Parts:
C1-EP-DR: 10uF; NORDIC_NRF_3_RESC0402_N
C2-EP-DR: 4.7uF/25V; ESP32_C6_LIBRARY_1_ESP32_WROVER_EAGLE-LTSPICE_C0402
C27: 0.1uF; NORDIC_NRF_3_RESC0402_N
C29, C30, C31, C32: 1uF; NORDIC_NRF_3_RESC0402_N
C34, C42: 0.1uF; NORDIC_NRF_3_RESC0201_N
C43: 4.7uF; NORDIC_NRF_3_RESC0402_N
D2, D4, D5: MBR0530; ESP32_C6_LIBRARY_5_SOD3716X135N
D3: USBLC6-2SC6Y; ESP32_C6_LIBRARY_3_SOT95P280X145-6N
EPD_C1, EPD_C2, EPD_C6, EPD_C7, EPD_C8, EPD_C9, EPD_C10, EPD_C11, EPD_C12: 1uF/50V; NORDIC_NRF_3_RESC0402_N
EPD_C5: 0.1uF/50V; NORDIC_NRF_3_RESC0402_N
IC2: DRV2605YZFR; DRV2605YZFR_BGA9C50P3X3_144X144X62
J1: 503480-2400; 503480-2400_5034802400
J4: KH-TYPE-C-16P; KH-TYPE-C-16P_KINGHELM_KH-TYPE-C-16P
L5: 68uH; ESP32_C6_LIBRARY_2_IND_4828-WE-TPC_WRE
Q1: 20V/4.2A/52mΩ/1.4W; ESP32_C6_LIBRARY_4_ESP32_C6_LIBRARY_4_ESP32_C6_LIBRARY_4_ES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
Q3: SI1308EDL-T1-GE3; ESP32_C6_LIBRARY_6_SOT65P210X110-3N
R1_EP_DR: 0.47; CPF0201D7K68C1_0201
R1_USB, R2_USB: 5K1; CPF0201D7K68C1_0201
R2_EP_DR: 10k; CPF0201D7K68C1_0201
R5, R7, R8: 10K; CPF0201D7K68C1_0201
R_PWR_EPD: 10k; CPF0201D7K68C1_0201
R_TYPE_SEL: 2.2; CPF0201D7K68C1_0201
SJ1: ESP32_C6_LIBRARY_7_JUMPER_SJ
SW_DN: 2025-10-22_07-23-44_LIBRARY_EVP-AKE31ASW_EVP-AKE3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; 2025-10-22_07-23-44_LIBRARY_SW_EVP-AKE31A_PAN
SW_ENT: 2025-10-22_07-23-44_LIBRARY_EVP-AKE31ASW_EVP-AKE3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; 2025-10-22_07-23-44_LIBRARY_SW_EVP-AKE31A_PAN
SW_UP: 2025-10-22_07-23-44_LIBRARY_EVP-AKE31ASW_EVP-AKE3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; 2025-10-22_07-23-44_LIBRARY_SW_EVP-AKE31A_PAN
TP_BAT_GND: HECTOR_WATCH_1_TPTP20R; HECTOR_WATCH_1_TP20R
TP_ON: HECTOR_WATCH_1_TPTP20R; HECTOR_WATCH_1_TP20R
TP_OP: HECTOR_WATCH_1_TPTP20R; HECTOR_WATCH_1_TP20R
TP_VBAT: HECTOR_WATCH_1_TPTP20R; HECTOR_WATCH_1_TP20R
U3: MAX17048G+T10; ESP32_C6_LIBRARY_SON50P200X200X80-9N

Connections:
3V3: C34.1, IC2.C2 (VDD), Q1.2 (S), R5.2, R7.2, R8.2, R_PWR_EPD.2; also elsewhere on the board
ALERT: U3.5 (!ALERT); also elsewhere on the board
DN: D3.1 (I/O1_1), J4.A7 (DN1), J4.B7 (DN2)
DP: D3.3 (I/O2_1), J4.A6 (DP1), J4.B6 (DP2)
D_N: D3.6 (I/O1_2); also elsewhere on the board
D_P: D3.4 (I/O2_2); also elsewhere on the board
EPD_3V3: C1-EP-DR.1, EPD_C5.2, J1.15, J1.16, L5.2, Q1.3 (D)
EPD_BUSY: J1.9; also elsewhere on the board
EPD_CS: J1.12; also elsewhere on the board
EPD_DC: J1.11; also elsewhere on the board
EPD_RST: J1.10; also elsewhere on the board
GDR: J1.2, Q3.1 (G), R2_EP_DR.2
GND: C1-EP-DR.2, C27.1, C29.2, C30.1, C31.1, C32.1, C34.2, C42.2, C43.2, D3.2 (GND), D4.1 (K), EPD_C1.1, EPD_C2.1, EPD_C5.1, EPD_C6.1, EPD_C7.1, EPD_C8.1, EPD_C9.1, EPD_C10.1, EPD_C11.1, EPD_C12.1, IC2.B1 (IN/TRIG), IC2.B3 (GND), J1.8, J1.17, J1.MP1, J1.MP2, J4.A1_B12 (GND), J4.A12_B1 (GND), J4.SH1 (SHIELD), J4.SH2 (SHIELD), J4.SH3 (SHIELD), J4.SH4 (SHIELD), R1_USB.1, R2_EP_DR.1, R2_USB.2, R_TYPE_SEL.1, SJ1.1, SW_DN.1, SW_ENT.1, SW_UP.1, TP_BAT_GND.TP, U3.1 (CTG), U3.4 (GND), U3.6 (QSTRT), U3.9 (EP); also elsewhere on the board
HAPTIC_EN: IC2.A1 (EN); also elsewhere on the board
MOSI: J1.14; also elsewhere on the board
unnamed: J4.A5 (CC1), R1_USB.2
unnamed: J4.B5 (CC2), R2_USB.1
unnamed: C2-EP-DR.2, D5.2 (A), L5.1, Q3.3 (D)
unnamed: EPD_C6.2, J1.18
unnamed: EPD_C7.2, J1.19
unnamed: EPD_C8.2, J1.20
unnamed: C2-EP-DR.1, D2.1 (K), D4.2 (A)
unnamed: EPD_C2.2, J1.4
unnamed: EPD_C1.2, J1.5
unnamed: R1_EP_DR.1, R_TYPE_SEL.2, SJ1.2
unnamed: EPD_C10.2, J1.22
unnamed: EPD_C12.2, J1.24
unnamed: C32.2, IC2.A2 (REG)
OUT+: IC2.A3 (OUT+), TP_OP.TP
OUT-: IC2.C3 (OUT-), TP_ON.TP
P0.13: C30.2, R5.1, SW_UP.2; also elsewhere on the board
P0.14: C31.2, R8.1, SW_ENT.2; also elsewhere on the board
P1.01: Q1.1 (G), R_PWR_EPD.1; also elsewhere on the board
P1.02: C29.1, R7.1, SW_DN.2; also elsewhere on the board
PREVGH: D5.1 (K), EPD_C9.2, J1.21
PREVGL: D2.2 (A), EPD_C11.2, J1.23
RESE: J1.3, Q3.2 (S), R1_EP_DR.2
SCK: J1.13; also elsewhere on the board
SCL: IC2.C1 (SCL), U3.7 (SCL); also elsewhere on the board
SDA: IC2.B2 (SDA), U3.8 (SDA); also elsewhere on the board
VBAT: C27.2, TP_VBAT.TP, U3.2 (CELL), U3.3 (VDD); also elsewhere on the board
VBUS: C42.1, C43.1, D3.5 (VBUS), J4.A4_B9 (VBUS), J4.A9_B4 (VBUS); also elsewhere on the board

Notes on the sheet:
DMG2305UX-7
E-Paper Drive Circuit
E-Paper Display Connector
Fuel Gauge
Haptic Driver
E-Paper & Peripherals
Drawn by: Clarisse Braviceanu Badea
USB C Connector & ESD Protection

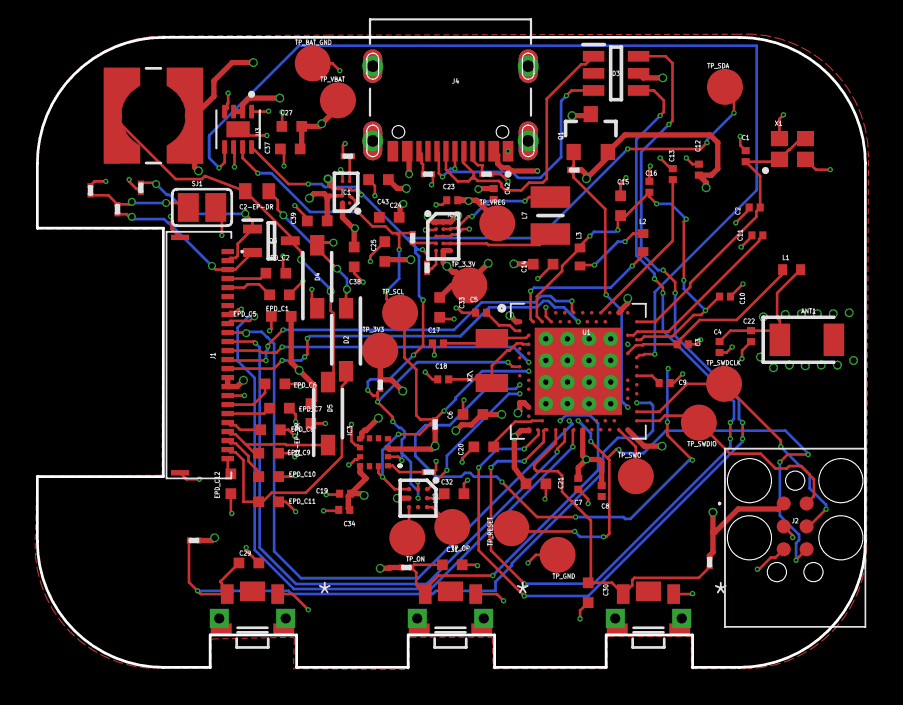
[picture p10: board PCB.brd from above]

Board: 4 copper layers, 46.0 x 35.0 mm, 105 parts (0 on the bottom side), 66 nets.

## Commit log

2026-04-21 updated project
    [Electronics Design.f3z, PCB.brd, Schematic.sch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]
2026-04-21 updated schematic.pdf
2026-04-22 Updated Schematic

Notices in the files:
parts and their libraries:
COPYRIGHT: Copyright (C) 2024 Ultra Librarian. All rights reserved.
